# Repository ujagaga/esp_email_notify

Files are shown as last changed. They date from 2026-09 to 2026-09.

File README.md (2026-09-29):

# ESP Email Notify

A small desk gadget that tells you when specific people email you, and lets you
send one of a few canned replies with the press of a button.

An ESP8266 with a Nokia 5110 LCD, a piezo speaker and two buttons shows the
latest unread mail from a list of watched senders and beeps when a new one
arrives. One button cycles through the prepared responses, the other sends the
selected one as a reply.

## How it works

```
  Gmail API  <--HTTPS/OAuth-->  Python server  <--HTTP on LAN-->  ESP8266
                                (this computer)                   (LCD, beep, buttons)
```

- **The server does all the mail work.** It holds the Google OAuth token,
  queries Gmail for unread mail from the configured senders, sends replies and
  marks replied mail as read. The ESP never talks to Google and holds no Google
  credentials. It is only a display, speaker and pair of buttons.
- **Polling, not push.** The ESP asks the server `/check` every few seconds,
  and each request makes the server query Gmail. The server only tells the ESP
  to beep once for each new message.
- **Zero-config discovery.** Server and ESP are on the same local network. The
  ESP broadcasts `email_check?` over UDP, and the server answers with its HTTP
  port. The ESP reads the server's IP from the reply, so neither side needs a
  static IP.
- **Replies in the thread.** Pressing OK sends the selected response as a
  normal reply to the shown message, then marks it read in Gmail.
- **Simple device setup.** After every start the ESP runs its own WiFi access
  point for 5 minutes, with a web page for choosing the home network. After
  that it switches to client-only mode.
- **Personal-use Google app.** The OAuth app is published but unverified, and
  asks for the single `gmail.modify` scope. Sign-in happens once, in a browser
  on the server machine. After that the server runs unattended on the saved
  refresh token.

## Repository layout

| Folder | What it is |
|---|---|
| [PythonServer/](PythonServer/) | Flask server: Gmail access, web page to sign in and edit senders and responses, device API, UDP discovery. Setup and API are described in its [README](PythonServer/README.md). |
| [ESP8266_client/](ESP8266_client/) | Arduino firmware for the ESP8266 D1 mini: wiring, build, flashing and WiFi setup are described in its [README](ESP8266_client/README.md). |

## Getting started

1. Set up and start the server ([PythonServer/README.md](PythonServer/README.md)),
   then sign in at `http://localhost:<port>` on the same machine.
2. Build and flash the firmware, then connect it to your WiFi
   ([ESP8266_client/README.md](ESP8266_client/README.md)).
3. The ESP finds the server by itself and starts showing mail.

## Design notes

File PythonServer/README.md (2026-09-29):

# Email checker server

Flask service that checks Gmail for unread mail from configured senders and
reports it to the ESP8266, which is just a display/beep drone.

## Setup

1. In [Google Cloud Console](https://console.cloud.google.com/), create a
   project, enable the **Gmail API**, and create an OAuth client ID of type
   **Web application**. Add `<server-url>/oauth2callback` as an authorized
   redirect URI (Google allows only `https://...` or `http://localhost:<port>`).
   Download it as `credentials.json` into this folder.
2. Copy `config.py.example` to `config.py` and fill in:
   - `DEVICE_KEY`: a GUID for the ESP to authenticate with (generate one with
     `python -c "import uuid; print(uuid.uuid4())"`).
   - `SENDERS`: list of email addresses to watch for.
   - `ADMIN_EMAIL`: the Gmail account to check; the only one allowed to sign in.
   - `DISCOVERY_PORT`: UDP port for finding the server. Broadcasting
     `email_check?` to it gets the reply `email_check:<PORT>` from the server's IP.
3. Install dependencies: `pip install -r requirements.txt`
4. Run the server: `python app.py`

   Or run `./install.sh` instead of steps 3 and 4: it creates `.venv`, installs
   the packages and sets up the `email-notify-server` systemd service, which
   starts `run_server.sh` on boot.
5. Open `<server-url>` in a browser and sign in with `ADMIN_EMAIL`. This saves
   `token.json` (with a refresh token), after which the server runs unattended.
   While signed in, the page shows the current mail status.

## API

`GET /check`, header `X-Api-Key: <device_key>`

Response:
```json
{"beep": true, "message": "New mail - Alice: Meeting notes", "id": "18c2f...", "responses": ["On my way", "Call you later"]}
```

`beep` is `true` only when the reply contains unread mail that was not in the
previous `/check` reply, so the ESP beeps once per new message. `id` (the
latest unread message) and `responses` (edited on the `/config` page) are only
present when there is unread mail.

`POST /send`, header `X-Api-Key: <device_key>`, form fields `id` (message id
from `/check`) and `text` (reply body). Replies to that message's sender in the
same thread from the `ADMIN_EMAIL` Gmail account, then marks the message read.

```bash
curl -H "X-Api-Key: <device_key>" --data-urlencode "id=18c2f..." \
     --data-urlencode "text=On my way" <server-url>/send
```

Response: `{"ok": true}`, or `{"error": "..."}` with status 400/401/503.

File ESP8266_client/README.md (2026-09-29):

# ESP Email Notify

A small standalone gadget that checks a mailbox for **unread emails from specific
senders** and alerts you with a message on an old Nokia 5110 LCD and a few beeps
from a piezo speaker.

## Hardware

- ESP8266 D1 mini
- Nokia 5110 LCD module (PCD8544 controller, 84x48 pixels)
- Piezo speaker (passive buzzer)
- 2x push button
- Breadboard + jumper wires
- 330 Ω resistor (LCD backlight, optional)

## Wiring

| Nokia 5110 pin | D1 mini pin | GPIO | Notes |
|---|---|---|---|
| VCC | 3V3 | - | Module is 3.3V only, do not use 5V |
| GND | G | - | |
| SCLK | D5 | GPIO14  | Hardware SPI clock (SCK) |
| DIN (MOSI) | D7 | GPIO13  | Hardware SPI data (MOSI) |
| D/C | D2 | GPIO4 | Data/command select |
| RST | D1 | GPIO5 | Reset |
| CE (CS) | D8 | GPIO15  | Hardware SPI chip select |
| BL (backlight)  | 3V3 | - | Through 330 Ω resistor, or GND if it's active-low on your module |

| Piezo speaker | D1 mini pin | GPIO | Notes |
|---|---|---|---|
| + | D6 | GPIO12 | |
| - | G | - | |

| Push button | D1 mini pin | GPIO | Notes |
|---|---|---|---|
| Button 1 | D3 | GPIO0  | Other leg to GND, use internal pull-up |
| Button 2 | D4 | GPIO2  | Other leg to GND, use internal pull-up |

Don't hold either button pressed while the board powers up or resets: GPIO0
low selects flash mode and GPIO2 must be high at boot.

Free pins for later use: D0, RX, TX, A0.

## Schematic

```
  Nokia 5110 LCD                          Piezo speaker
  ,-------------.                         ,--------.
  | VCC  --------- 3V3 (D1 mini)          | +  ---- D6 (D1 mini)
  | GND  --------- GND (D1 mini)          | -  ---- GND (D1 mini)
  | SCLK --------- D5  (D1 mini)          `--------'
  | DIN  --------- D7  (D1 mini)
  | D/C  --------- D2  (D1 mini)
  | RST  --------- D1  (D1 mini)
  | CE   --------- D8  (D1 mini)
  | BL   --------- 3V3 (D1 mini, via 330R)
  `-------------'

  Push buttons (other leg of each to GND, internal pull-up)
  Button 1 ---- D3 (D1 mini)
  Button 2 ---- D4 (D1 mini)
```

## Setup

1. `tools/install_dependencies.sh`
2. Copy `config.h.example` to `config.h` and set `DEVICE_KEY` to the server's
   `DEVICE_KEY` (see `PythonServer/config.py`).
3. Build and flash: `tools/build.sh`, `tools/upload_usb.sh`
4. On first start, connect to the WiFi AP shown on the LCD
   (`AP_NAME` from `config.h`, password `PASSWORD`), open `http://192.168.4.1`
   and save your network. The device restarts and joins it.

After every start the setup AP stays up for `AP_MODE_TIMEOUT_S` (5 min) in
AP+STA mode. After that the device switches to STA only once no one is
connected to the AP.

## Behaviour

- Finds the server by broadcasting `email_check?` to UDP `DISCOVERY_PORT`, and
  looks again if the server stops answering.
- Polls the server's `/check` every `UPDATE_TIMEOUT` ms and shows the result on
  the LCD. New mail plays a short 3-tone beep.
- **Button 1 (D3)** cycles through the server's responses, shown inverted at
  the bottom of the LCD.
- **Button 2 (D4)** sends the selected response as a reply to the shown mail,
  which is then marked read.

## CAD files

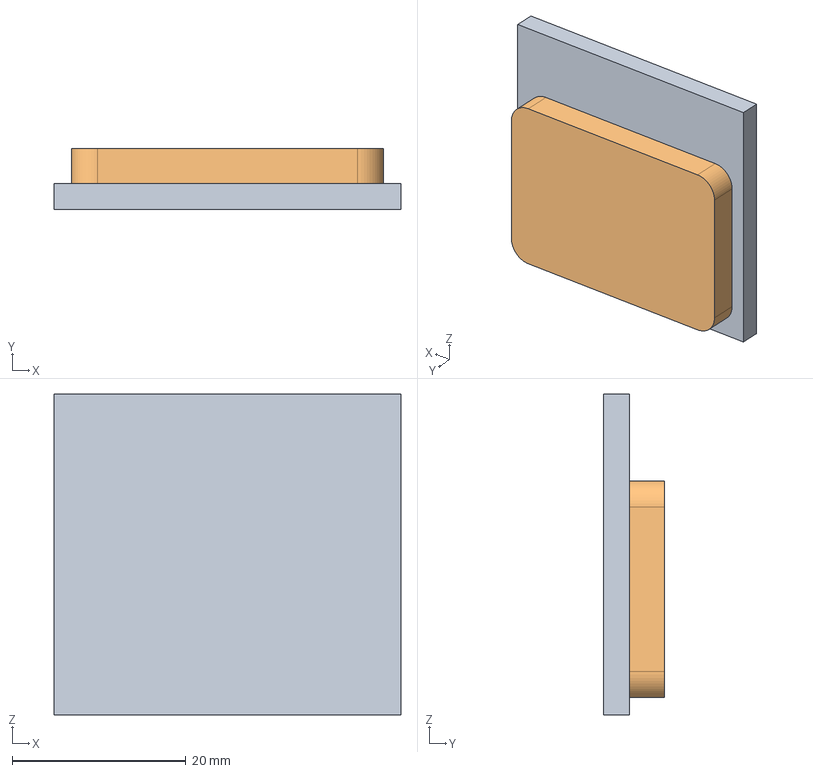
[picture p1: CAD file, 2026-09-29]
ESP8266_client/docs/casing.FCStd
40.0 x 7.00 x 37.0 mm

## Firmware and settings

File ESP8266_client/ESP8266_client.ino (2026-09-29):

/*
 *  Author: Rada Berar
 *  email: ujagaga@gmail.com
 *
 *  This is the main sketch file.
 *  It provides a periodic pooling of other services.
 */

#include "HardwareSerial.h"
#include "config.h"
#include "http_client.h"
#include "http_server.h"
#include "ui.h"
#include "wifi_connection.h"

static String statusMessage =
    ""; /* This is set and requested from other modules. */

void MAIN_setStatusMsg(String msg) { statusMessage = msg; }

String MAIN_getStatusMsg(void) { return statusMessage; }

void setup(void) {
  /* Need to wait for background processes to complete. Otherwise trouble with
   * gpio.*/
  delay(100);
  Serial.begin(115200);
  UI_init();
  WIFIC_init();
  HTTP_SERVER_init();
}

void loop(void) {
  if (WIFIC_isApMode()) {
    HTTP_SERVER_process();
  }
  HTTP_CLIENT_process(); /* Does nothing until STA is connected */

  WIFIC_process();
  UI_process();
}

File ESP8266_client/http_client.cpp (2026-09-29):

/*
 *  Author: Rada Berar
 *  email: ujagaga@gmail.com
 *
 *  Finds the server on the local network, polls it for new mail and sends
 *  the selected response.
 */
#include "config.h"
#include "ui.h"
#include <ArduinoJson.h>
#include <ESP8266HTTPClient.h>
#include <ESP8266WiFi.h>
#include <WiFiUdp.h>

#define MAX_RESPONSES 8

static unsigned long lastConnectAtemptTime = 0;
static String serverUrl = ""; /* Empty until discovered */

/* Broadcast "email_check?" and wait for "email_check:<port>" from the server */
static void discoverServer(void) {
  WiFiUDP udp;
  udp.begin(DISCOVERY_PORT);
  udp.beginPacket(IPAddress(255, 255, 255, 255), DISCOVERY_PORT);
  udp.print("email_check?");
  udp.endPacket();

  unsigned long start = millis();
  while ((millis() - start) < 1000) {
    if (udp.parsePacket() > 0) {
      String reply = udp.readString();
      if (reply.startsWith("email_check:")) {
        serverUrl = "http://" + udp.remoteIP().toString() + ":" + reply.substring(12);
        Serial.println("Server found: " + serverUrl);
        break;
      }
    }
    delay(10);
  }
  udp.stop();
}

static void checkMail(void) {
  WiFiClient client;
  HTTPClient http;
  http.begin(client, serverUrl + "/check");
  http.addHeader("X-Api-Key", DEVICE_KEY);
  int httpCode = http.GET();

  if (httpCode <= 0) {
    Serial.printf("HTTP GET failed, error: %s\n", http.errorToString(httpCode).c_str());
    serverUrl = ""; /* Server may have moved, look for it again */
    UI_showText("Server lost");
    http.end();
    return;
  }

  String response = http.getString();
  http.end();
  Serial.print("HTTP RX:");
  Serial.println(response);

  JsonDocument doc;
  if (deserializeJson(doc, response) != DeserializationError::Ok) {
    return;
  }

  String responses[MAX_RESPONSES];
  int count = 0;
  for (JsonVariant r : doc["responses"].as<JsonArray>()) {
    if (count < MAX_RESPONSES) {
      responses[count++] = r.as<String>();
    }
  }

  UI_setMail(doc["id"] | "", doc["message"] | "", responses, count);
  if (doc["beep"] | false) {
    UI_beep();
  }
}

static String urlEncode(String text) {
  String encoded = "";
  for (char c : text) {
    if (isalnum(c) || (c == '-') || (c == '_') || (c == '.') || (c == '~')) {
      encoded += c;
    } else {
      char hex[4];
      snprintf(hex, sizeof(hex), "%%%02X", (uint8_t)c);
      encoded += hex;
    }
  }
  return encoded;
}

bool HTTP_CLIENT_send(String id, String text) {
  if (serverUrl.length() == 0) {
    return false;
  }

  WiFiClient client;
  HTTPClient http;
  http.begin(client, serverUrl + "/send");
  http.addHeader("X-Api-Key", DEVICE_KEY);
  http.addHeader("Content-Type", "application/x-www-form-urlencoded");
  int httpCode = http.POST("id=" + id + "&text=" + urlEncode(text));
  http.end();

  lastConnectAtemptTime = 0; /* Check again right away */
  return httpCode == 200;
}

void HTTP_CLIENT_process() {
  if (WiFi.status() != WL_CONNECTED) {
    return;
  }

  if (((millis() - lastConnectAtemptTime) > (UPDATE_TIMEOUT + random(100))) ||
      (lastConnectAtemptTime == 0)) {
    if (serverUrl.length() == 0) {
      UI_showText("Looking for\nserver...");
      discoverServer();
    }
    if (serverUrl.length() > 0) {
      checkMail();
    }
    lastConnectAtemptTime = millis();
  }
}
